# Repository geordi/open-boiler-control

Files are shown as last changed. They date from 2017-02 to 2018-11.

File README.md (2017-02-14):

# Open Boiler Control
Modest attempt to control home brown coal boiler

# Goals
This is my attemt to implement controlling software for my home brown coal boiler
that is currently controlled by the Siemens Climatix PLC. The new controller has to
be able to:

* Control ventilator power
* Control coal feeder motor
* Monitor all temperatures and run boiler at optimal operating temeratures
* Control itself using equitherm curve

## Monitored Temperatures

* Outside temperature
* Boiler temperature (water temperature in the boiler)
* Exhausts temperature
* Heating circuit temperature (hot water to radiators)
* Heating circuit return (cold water from radiators)
* Hot water cylinder temperature

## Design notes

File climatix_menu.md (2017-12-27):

+ Date
+ Boiler Mode
+ Boiler Status
+ Current Output
|- 30% Wooden Pellet
| |- 20% - 100%
|- 100% Wooden Pellet
| |- 20% - 100%
|- 30% Brown Coal
| |- 20% - 100%
|- 100% Brown Coal
| |- 20% - 100%
|- 30% Other Fuel
| |- 20% - 100%
|- 100% Other Fuel
  |- 20% - 100%
+ Fuel Dosage
|- Serving Time
|- Delay Tome
|- 30% Wooden Pellet
| |- 5s - 200s
|- 100% Wooden Pellet
| |- 5s - 200s
|- 30% Brown Coal
| |- 5s - 200s
|- 100% Brown Coal
| |- 5s - 200s
|- 30% Other Fuel
| |- 5s - 200s
|- 100% Other Fuel
  |- 5s - 200s
+ B9 Outside Temperature
+ B2 Boiler Temperature
|- Current Requested Temperature
|- Min. Boiler Temperature
|- Max. Boiler Temperature
|- Hysteresis of Operating Boiler
|- Hysteresis of Switched Off Boiler
|- External Input
+ B7 Reverse Temperature
+ B8 Combustion Temperature
+ B1 HC1 Water Temperature (Heating Circuit 1)
+ A6 HC1 Room Temperature
+ B3 Hot Water Temperature
+ Fuel
+ User Menu
+ Servis Menu
+ Input Password
+ Application Name C26

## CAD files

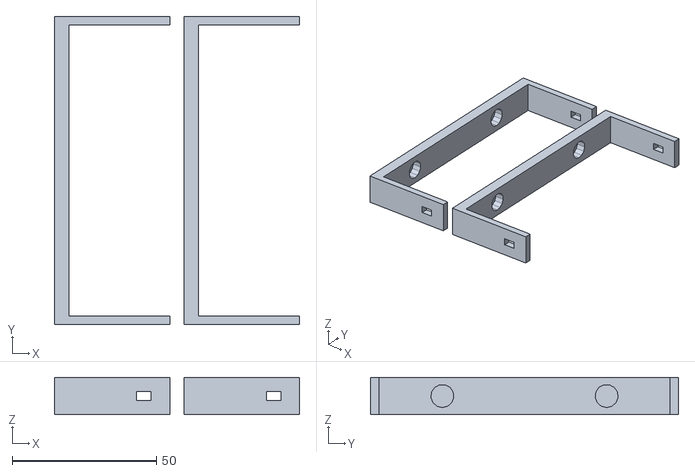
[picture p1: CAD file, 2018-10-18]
3d_printing/main_plate_clip.stl
85.0 x 107.0 x 13.0

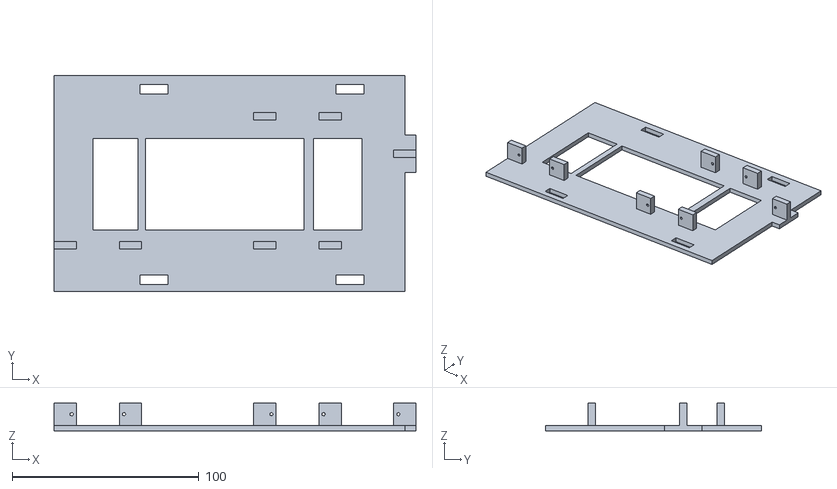
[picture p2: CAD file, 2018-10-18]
3d_printing/climatix.stl
194.0 x 116.0 x 15.0

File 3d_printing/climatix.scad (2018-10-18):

body_width = 173;
body_height = 97;
body_thickness = 0;//17;

servo_width = 23;
servo_height = 22;
servo_thickness = 12;

holder_thickness = 3;


module button() {
    translate([0, 0, body_thickness]) {
        cube([20, 13, 2]);
    }
}


module climatix_body() {
    //translate([0, 0, -body_thickness]) {
    cube([body_width, body_height, body_thickness]);

    translate([17, 27, 0]) {button();}
    translate([17, 42, 0]) {button();}
    translate([17, 57, 0]) {button();}

    translate([body_width - 17 - 20, 27, 0]) {button();}
    translate([body_width - 17 - 20, 42, 0]) {button();}
    translate([body_width - 17 - 20, 57, 0]) {button();}
}


module rod() {
    w = 21;
    h = 4;

    hull() {
        cylinder(h=2,r=4); 
        translate([15, 0, 0]) { cylinder(h=2, r=2); }
    }
    cylinder(h=4,r=4); 
}


module servo(rod_angle=180, enable_servo_body=true, left_holder=true, right_holder=true) {
    if ( enable_servo_body ) {
        cube([servo_width, servo_height, servo_thickness]); // servo main body
        difference() { // holding plate
            translate([-5, 18, 0]) { cube([32, 3, servo_thickness]); }
            translate([-2.5, 22, servo_thickness / 2]) { rotate([90, 0, 0]) { cylinder(h=10, r=1); } }
            translate([servo_width + 2.5, 22, servo_thickness / 2]) { rotate([90, 0, 0]) { cylinder(h=10, r=1); } }
        }

        // gearbox and axle
        translate([servo_thickness / 2, 0, servo_thickness / 2]) { rotate([-90, 0, 0]) { cylinder(h=servo_height + 6, r = servo_thickness / 2); } }
        translate([servo_thickness, 0, servo_thickness / 2]) { rotate([-90, 0, 0]) { cylinder(h=servo_height + 6, r = 2.5); } }
        translate([servo_thickness / 2, 0, servo_thickness / 2]) { rotate([-90, 0, 0]) { cylinder(h=servo_height + 10, r = 2.5); } }

        translate([servo_thickness / 2, 30 + 4, servo_thickness / 2]) { rotate([90, rod_angle, 0]) { rod(); } }
    }

    if ( left_holder ) {
        servo_holder_left();
    }
    if ( right_holder ) {
        servo_holder_right();
    }
}


module main_plate_holder() {
    union() {
        difference() {
            translate([-6, 0, body_thickness]) { cube([body_width + 15, body_height, holder_thickness]); }
            translate([15, 24, 0]) { cube([20 + 4, 13 * 3 + 2 * 2 + 6, 60]); }
            translate([body_width - 17 - 20 - 3, 24, 0]) { cube([20 + 6, 13 * 3 + 2 * 2 + 6, 60]); }
            translate([17 + 20 + 6, 24, 0]) { cube([85, 49, 60]); }
        }
        
        // extended piece to support right middle servo
        translate([body_width, 55, body_thickness]) { cube([15, 20, holder_thickness]); }

        difference() {
            translate([-6, -10 + 1, body_thickness]) { cube([body_width + 15, 10 + 1, holder_thickness]); }
            translate([40, -5, 0]) { cube([15, 5, 40]); }
            translate([145, -5, 0]) { cube([15, 5, 40]); }
        }
        difference() {
            translate([-6, body_height - 1, body_thickness]) { cube([body_width + 15, 10 + 1, holder_thickness]); }
            translate([40, body_height, 0]) { cube([15, 5, 40]); }
            translate([145, body_height, 0]) { cube([15, 5, 40]); }
        }

    }

    // holders for 3D printer
    //translate([-5, -5, body_thickness]) { cylinder(r=10, h=3); }
    //translate([body_width + 5, -5, body_thickness]) { cylinder(r=10, h=3); }
    //translate([-5, body_height + 5, body_thickness]) { cylinder(r=10, h=3); }
    //translate([body_width + 5, body_height + 5, body_thickness]) { cylinder(r=10, h=3); }

}


module servo_holder_left() {
    servo_holder_height = 4;
    difference() {
        translate([-12, 18 - servo_holder_height, 0]) { cube([12, servo_holder_height, servo_thickness]); }
        translate([-2.5, 22, servo_thickness / 2]) { rotate([90, 0, 0]) { cylinder(h=10, r=1); } }
    }
}


module servo_holder_right() {
    servo_holder_height = 4;
    difference() {
        translate([servo_width, 18 - servo_holder_height, 0]) { cube([12, servo_holder_height, servo_thickness]); }
        translate([servo_width + 2.5, 22, servo_thickness / 2]) { rotate([90, 0, 0]) { cylinder(h=10, r=1); } }
    }
}


enable_vitamins = false;
enable_servos = false;

if ( enable_vitamins ) {
    climatix_body();
}

main_plate_holder();


// bottom left
translate([6, 0, holder_thickness + body_thickness]) {
  rotate([0, 0, 0]) { servo(25, enable_servos); }
}

// bottom right
//translate([body_width - 37, 0, holder_thickness + body_thickness + servo_thickness]) {
//  rotate([0, 180, 0]) { servo(205, enable_servos); }
//}
translate([body_width - 37 - servo_width, 0, holder_thickness + body_thickness]) {
  rotate([0, 0, 0]) { servo(25, enable_servos); }
}

// top right
translate([body_width - 37, body_height + 4, holder_thickness + body_thickness]) {
  rotate([180, 180, 0]) { servo(155, enable_servos); }
}

// middle right
translate([153, 81, holder_thickness + body_thickness + servo_thickness]) {
  rotate([180, 0, 0]) { servo(205, enable_servos, false, true); }
}

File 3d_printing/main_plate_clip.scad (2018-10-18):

body_width = 173;
body_height = 97;
body_thickness = 21;

servo_width = 23;
servo_height = 22;
servo_thickness = 12;

holder_thickness = 4;

clip_width = 13;
clip_thickness = 4;

module holder_plate_clip(x=0, y=0, z=0) {

    difference() {
        union() {
            // sides
            translate([x, y, z]) { cube([clip_width, clip_thickness-1, 40]); }
            translate([x, y + 7 + body_height, z]) { cube([clip_width, clip_thickness - 1, 40]); }

            translate([x, y, z]) { cube([clip_width, body_height + 10, 5]); } // bottom plate
        }
        translate([x + (clip_width / 2) - (3 / 2), y - 5, holder_thickness + 1 + 23.5/*z + 5 + body_thickness + holder_thickness*/]) { cube([3, body_height + 20, 5]); } // hole
        translate([clip_width / 2, 25, 1]) { cylinder(10, 4, 4, [0, 0, 0]); };
        translate([clip_width / 2, 82, 1]) { cylinder(10, 4, 4, [0, 0, 0]); };

    }
}


translate([0, 0, clip_width]) { rotate([0, 90, 0]) { holder_plate_clip(); } }
translate([45, 0, clip_width]) { rotate([0, 90, 0]) { holder_plate_clip(); } }

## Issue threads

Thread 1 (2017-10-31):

interesting project, any updates?

hbakhtiyor, 2017-10-31:

geordi, 2017-10-31:
Well, I split the project into two parts. The first is to be able to control my current Siemens Climatics controller using MG90S servos. That's the goal for this winter. The second is to reimplement the whole control unit.

Just ordered servos, so I'm waiting for the to arrive.

hbakhtiyor, 2017-11-04:
nice, maybe to make video about your automation controller, how it works, how to firmware, ...

are your codes suitable only for siemens controller? or any plc?

hbakhtiyor, 2017-11-13:
@geordi any updates?

geordi, 2017-11-14:
My boiler is controlled by Siemens Climatix, which is a PLC and it's locked. So the only way to remotely control it thought it's control panel using some servos in a similar way is in [this video](https://www.youtube.com/watch?v=migRN4P1wGI). Instead of ESP8266, I'm planing to use Arduino. So I'm not planing to directly program the PLC.

I'll post the Siemens Climatix menu structure to be more clear about it.

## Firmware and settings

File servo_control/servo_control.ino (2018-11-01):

// https://electronics.stackexchange.com/questions/77502/is-there-a-way-to-stop-servos-from-shaking

#include <Servo.h>

#define NO_SERVOS          4

#define SERVO_BACK         0
#define SERVO_UP           1
#define SERVO_DOWN         2
#define SERVO_ENTER        3

#define SERVO_PIN_BACK     9
#define SERVO_PIN_UP      10
#define SERVO_PIN_DOWN    11
#define SERVO_PIN_ENTER    6

#define ANGLE_PUSH        20
#define ANGLE_RETRACT     10

#define INIT_SERVO_ANGLE   ANGLE_RETRACT // init servo position in degrees

#define SERVO_COMMAND_DELAY 350

int servo_pins[ NO_SERVOS ] = { SERVO_PIN_BACK, SERVO_PIN_UP, SERVO_PIN_DOWN, SERVO_PIN_ENTER };
int servo_init_angles[ NO_SERVOS ] = { 77, 30, 95, 95 };

Servo servos[ NO_SERVOS ];  

int servo_back_angle_push = 97;
int servo_back_angle_retract = 77;

int servo_up_angle_push = 10;
int servo_up_angle_retract = 30;

int servo_down_angle_push = 115;
int servo_down_angle_retract = 95;

int servo_enter_angle_push = 115;
int servo_enter_angle_retract = 95;


void setup()
{
    for ( int i = 0; i < NO_SERVOS; i++ ) {
        pinMode( servo_pins[ i ], INPUT );
    }

    Serial.begin(115200);

    for ( int i = 0; i < NO_SERVOS; i++ ) {
        servos[ i ].attach( servo_pins[ i ] );
        delay( SERVO_COMMAND_DELAY );
        pinMode( servo_pins[ i ], OUTPUT );
        servos[ i ].write( servo_init_angles[ i ] );
        delay( SERVO_COMMAND_DELAY );
        pinMode( servo_pins[ i ], INPUT );
    }
}
 

void push_and_release_button( int servo_id ) {
    // BACK - positive angle to push
    // UP - negative
    // DOWN - positive angle to push
    // ENTER - positive angle to push

    int angle_push = ANGLE_PUSH;
    int angle_retract = ANGLE_RETRACT;

    if ( servo_id == SERVO_BACK ) {
        angle_push = servo_back_angle_push;
        angle_retract = servo_back_angle_retract;
    }
    else if ( servo_id == SERVO_UP ) {
        angle_push = servo_up_angle_push;
        angle_retract = servo_up_angle_retract;
    }
    else if ( servo_id == SERVO_DOWN ) {
        angle_push = servo_down_angle_push;
        angle_retract = servo_down_angle_retract;
    }
    else if ( servo_id == SERVO_ENTER ) {
        angle_push = servo_enter_angle_push;
        angle_retract = servo_enter_angle_retract;
    }

    Servo * servo = &servos[ servo_id ];
    //delay( SERVO_COMMAND_DELAY );
    pinMode( servo_pins[ servo_id ], OUTPUT );
    delay( 10 );
    
    servo->write( angle_push );
    
    delay( SERVO_COMMAND_DELAY );
    
    servo->write( angle_retract );
    
    delay( SERVO_COMMAND_DELAY );
    pinMode( servo_pins[ servo_id ], INPUT );
    delay( 10 );
}


void loop()
{
    // Searial.setTimeout( 2000 )
  
    if ( Serial.available() > 0 ) {
        byte b[80];
        Serial.readBytes( b, 1 );
        //int incomming_command = Serial.read();
        byte incomming_command = b[ 0 ];

        //Serial.print( "Received:" );
        //Serial.println( i, DEC );

        if ( incomming_command == 'U' ) {
            push_and_release_button( SERVO_UP );
        }
        else if ( incomming_command == 'B' ) {
            push_and_release_button( SERVO_BACK );
        }
        else if ( incomming_command == 'D' ) {
            push_and_release_button( SERVO_DOWN );
        }
        else if ( incomming_command == 'E' ) {
            push_and_release_button( SERVO_ENTER );
        }
        else if ( incomming_command == 'L' ) {
            //Serial.println( "Load OP" );
            //Serial.readBytes( b, 1);
            //Serial.print( "Will update servo:" );
            //Serial.println( b[0] );
        }
    }
    /*
    push_and_release_button( SERVO_BACK );
    push_and_release_button( SERVO_UP );

    push_and_release_button( SERVO_DOWN );
    push_and_release_button( SERVO_ENTER );

    //test_up_button();
    
    delay( 2000 );
    */
    
   /*
   servos[ SERVO_BACK ].write(5);      // Turn SG90 servo Left to 45 degrees
   delay(1000);          // Wait 1 second
   servos[ SERVO_BACK ].write(10);      // Turn SG90 servo back to 90 degrees (center position)
   delay(1000);          // Wait 1 second
   servos[ SERVO_UP ].write(15);     // Turn SG90 servo Right to 135 degrees
   delay(1000);          // Wait 1 second
   servos[ SERVO_UP ].write(20);      // Turn SG90 servo back to 90 degrees (center position)
   delay(1000);
   */

//if you change the delay value (from example change 50 to 10), the speed of the servo changes
  /*
  for(servoAngle = 0; servoAngle < 180; servoAngle++)  //move the micro servo from 0 degrees to 180 degrees
  {                                  
    servo.write(servoAngle);              
    delay(50);                  
  }

  for(servoAngle = 180; servoAngle > 0; servoAngle--)  //now move back the micro servo from 0 degrees to 180 degrees
  {                                
    servo.write(servoAngle);          
    delay(10);      
  }
  */
  //end control the servo's speed  
}

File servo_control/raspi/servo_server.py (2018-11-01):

#!/usr/bin/env python3

import datetime
import logging
import os
import select
import serial
import socketserver
import sys
import time

from common import *

SERVER_HOST, SERVER_PORT = '0.0.0.0', PI_PORT

serial_port = None


class MyUDPHandler(socketserver.BaseRequestHandler):

    def handle(self):
        global serial_port
        data = self.request[0].strip()
        socket = self.request[1]
        print("{} wrote:".format(self.client_address[0]))
        print('Data:', data)
        data_decoded = data.decode()
        print('Data decoded:', data_decoded)
    
        if data_decoded in ('U', 'D', 'B', 'E'):
            serial_port.write(data)
        else:
            print('Unknown command: {}'.format(data_decoded))


class MyServer(socketserver.UDPServer):

    def __init__(self, server_address, handler_class=MyUDPHandler):
        socketserver.UDPServer.__init__(self, server_address, handler_class)


    def server_activate(self):
        socketserver.UDPServer.server_activate(self)


    def handle_request(self):
        return socketserver.UDPServer.handle_request(self)


def init_serial():
    global serial_port
    serial_port = serial.Serial('/dev/ttyUSB0', 115200)


def main():
    logging.basicConfig(filename=LOG_FILENAME, format='%(asctime)s %(levelname)s:%(message)s', level=logging.DEBUG)

    init_serial()

    server = MyServer((SERVER_HOST, SERVER_PORT), MyUDPHandler)

    while True:
        # this is relict from having second Arduino connected to the serial port
        input_ready, output_ready, except_ready = select.select([server], [], [])
        for s in input_ready:
            if s is server:
                logging.info('Receiving data on UDP server...')
                s.handle_request()


if __name__ == '__main__':
    main()

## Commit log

2017-02-11 Readme updated with monitored temperatures
2017-02-14 Added one more monitored temperature
2018-01-25 WIP: Holder for servo motors to control Climatix display
    [climatix.scad]
2018-01-26 WIP: Climatix servo motors holder updated
    [climatix.scad]
2018-02-04 Servos positions corrected
    [climatix.scad]
2018-02-05 Holder finalised + holder clips
    [climatix.scad, main_plate_clip.scad]
2018-02-06 Corner holders in main plate holder
    [climatix.scad]
2018-02-14 Correncted some errors after the first 3D print
    [climatix.scad, main_plate_clip.scad]
2018-10-18 3D model update that fits on Climatix
    [climatix.scad, main_plate_clip.scad]
2018-10-18 Added STL for visualization on GitHub
    [climatix.stl, main_plate_clip.stl]
2018-11-01 Web controller of servo buttons
